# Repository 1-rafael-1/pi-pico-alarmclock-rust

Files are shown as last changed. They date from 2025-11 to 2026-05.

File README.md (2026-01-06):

# Raspberry Pi Pico Alarmclock written in Rust



A fully-featured alarm clock built on a Raspberry Pi Pico W, written in Rust using the Embassy async framework.

<div align="center">
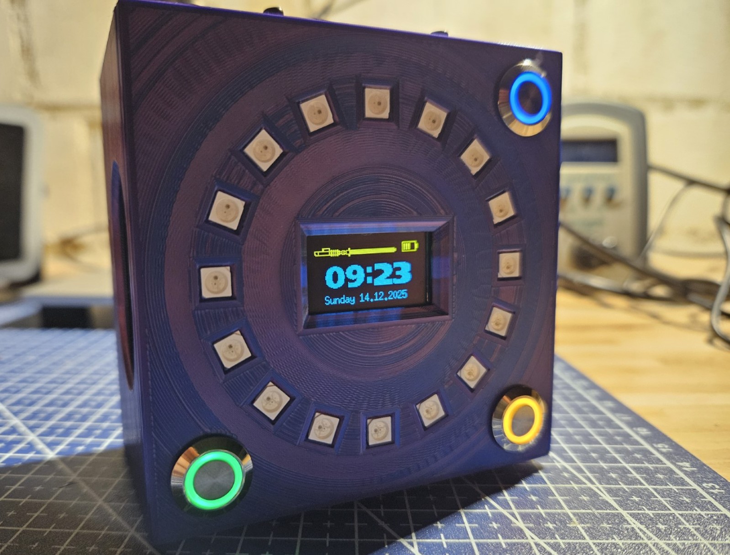
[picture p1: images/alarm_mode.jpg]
Alarm clock with alarm enabled
  
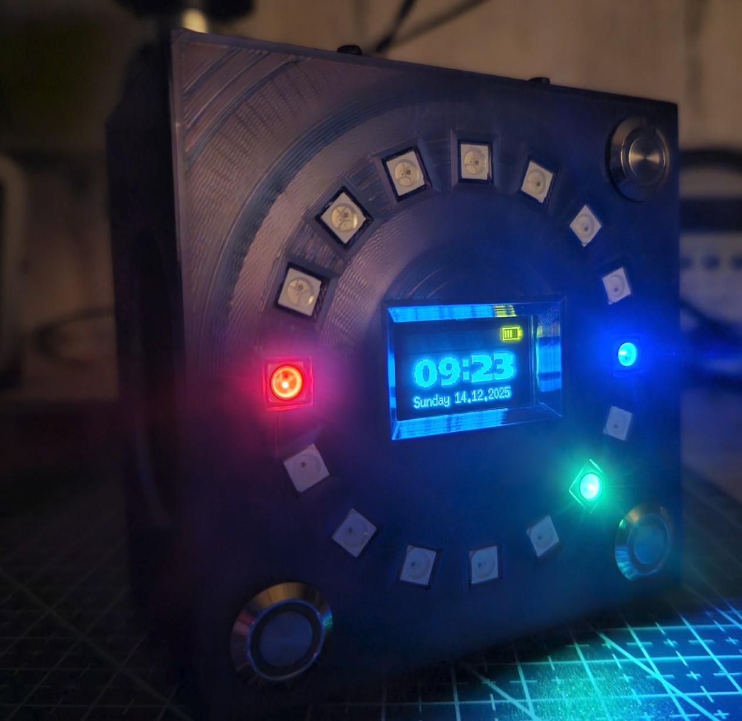
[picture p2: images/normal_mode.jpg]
Finished alarm clock front view
  
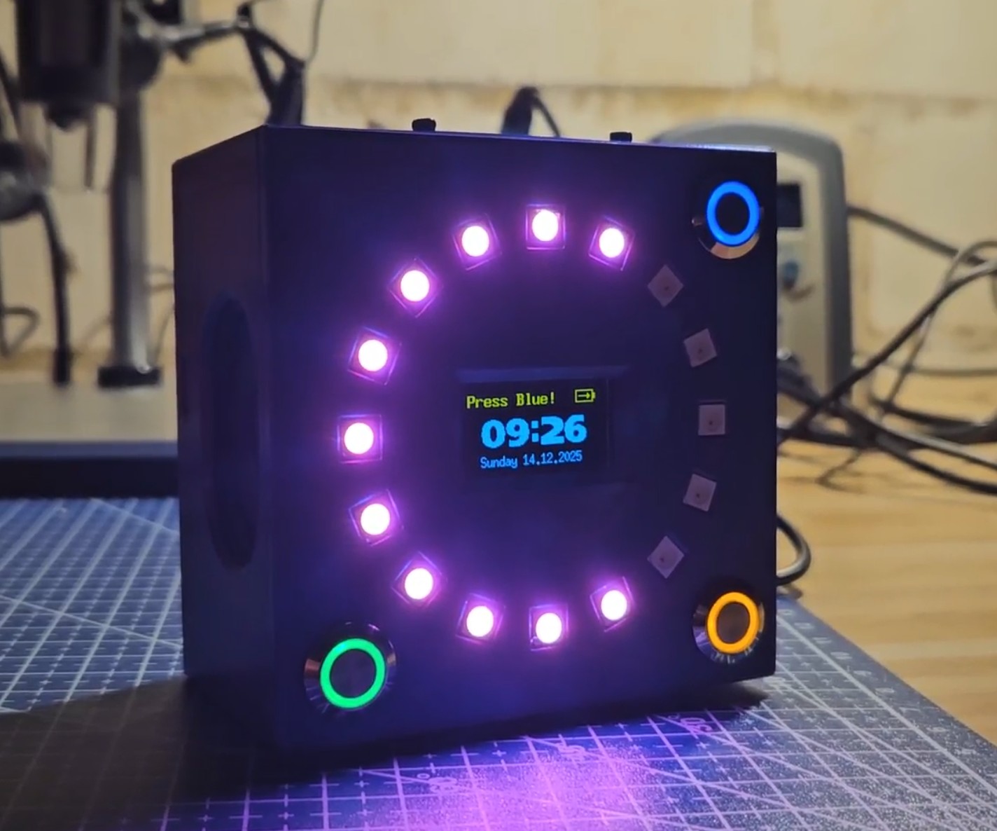
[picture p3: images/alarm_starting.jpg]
Finished alarm clock with LEDs active
  
</div>

*Left: Alarm enabled with lightsaber icon indicator. Center: The completed alarm clock showing the OLED display, NeoPixel ring with hour markers, and three illuminated control buttons (green, blue, yellow). Right: Alarm clock in operation with active NeoPixel LEDs displaying the analog clock.*

---

## Features at a Glance

### Core Functionality
- **WiFi Time Sync** - Automatic time synchronization via worldtimeapi.org (refreshed every 6 hours)
- **Alarm System** - Configurable alarm with sunrise light effect and audio playback
- **Visual Display** - 128×64 OLED display with custom Star Wars-inspired font
- **Analog Clock** - 16-LED NeoPixel ring showing hours (red), minutes (green), and seconds (blue)
- **Battery Powered** - 18650 Li-ion battery with USB charging and voltage monitoring

### User-Configurable Settings
- **Volume Control** (0-30) - Adjustable alarm sound volume, persisted to flash
- **LED Brightness** (0-20) - Adjustable NeoPixel clock brightness with live preview
- **Manual Time Setting** - Set time via buttons when WiFi unavailable or for DST adjustments

### Advanced Features
- **Multi-Mode Interface** - Normal, Menu, Settings, Alarm, System Info, and Standby modes
- **Smart Alarm** - Sunrise light effect followed by audio, with randomized button sequence to dismiss
- **Auto-Timeout Protection** - All menus and settings automatically return to Normal mode after 10 seconds of inactivity (with auto-save)
- **Power Management** - Standby mode with task suspension for minimal power consumption
- **Persistent Storage** - All settings saved to flash memory and survive power cycles

---

## Quick Start

### Build and Flash

This project uses **probe-rs** for debugging and flashing via a debug probe (e.g., Raspberry Pi Debug Probe, Picoprobe).

```bash
# Build and flash with probe-rs (recommended)
DEFMT_LOG=warn cargo run --release
```

See the [Building the Project](#building-the-project) section for more details.

### First Use

1. Power on the device - it will initialize and sync time via WiFi
2. Press **Yellow** to open the menu
3. Press **Green** to access Settings
4. Configure your preferences (volume, brightness, etc.)
5. Press **Blue** in Normal mode to set your alarm time
6. Press **Green** in Normal mode to toggle the alarm on/off

See the [User Manual](#user-manual) below for detailed instructions.

---

## Hardware Components

### Main Components
- Raspberry Pi Pico W (microcontroller with WiFi)
- SSD1306 OLED Display (128×64 pixels, I²C)
- DFPlayer Mini MP3 module (DFR0299)
- WS2812B NeoPixel Ring (16 RGB LEDs)
- 3W 8Ω Speaker
- 18650 Li-ion Battery (3350mAh)
- TC4056A Charger Module
- 5V Step-up Converter

### Interface
- 3× LED Ring Push Buttons (12mm, Green/Blue/Yellow)
- Micro SD card (FAT32, for alarm audio)

Complete bill of materials available in the [Components](#components-bill-of-materials) section below.

---

## Project Structure

The project is written in Rust using the Embassy async framework:

- **`src/state.rs`** - System state management
- **`src/event.rs`** - Event channel and event types
- **`src/task/`** - Async tasks for each peripheral and system function
  - `orchestrate.rs` - Central orchestration and state transitions
  - `display.rs` - OLED display management
  - `light_effects.rs` - NeoPixel LED control
  - `sound.rs` - DFPlayer audio control
  - `rtc_manager.rs` - Real-time clock management
  - `alarm_settings.rs` - Flash persistence for settings
  - `time_updater.rs` - WiFi time synchronization
  - And more...
- **`src/utility/`** - Helper functions (DateTime conversion, etc.)
- **`media/`** - Custom BMP graphics for display
- **`circuit/`** - KiCad schematic and PCB design
- **`enclosure/`** - FreeCAD 1.0 design files

### Documentation

```bash
# Generate and view code documentation
cargo doc --open
```

---

## Building the Project

This project uses `defmt` for logging. Log levels are controlled by the `DEFMT_LOG` environment variable.

### Development Build

For development with full logging (requires debug probe):

```bash
cargo build
cargo run
```

### Release Build

**Warnings only** (prevents RTT buffer overflow when running standalone):

```bash
DEFMT_LOG=warn cargo build --release
DEFMT_LOG=warn cargo run --release
```

**Moderate logging** (info and above):

```bash
DEFMT_LOG=info cargo build --release
```

## User Manual

### Button Layout

- **Green Button** (left)
- **Blue Button** (middle)
- **Yellow Button** (right)

---

### Normal Mode (Clock Display)

This is the default mode showing the current time.

| Button | Action |
|---|---|
| **Green** | Toggle alarm ON/OFF |
| **Blue** | Enter alarm time setting |
| **Yellow** | Open menu |

**Display shows:**
- Current time (large Star Wars font digits)
- Date and day of week
- Lightsaber icon (if alarm is active)
- Battery level or USB charging indicator

**NeoPixel ring:**
- Red LED = hour hand
- Green LED = minute hand
- Blue LED = second hand
- Colors mix when hands overlap

---

### Setting the Alarm Time

| Button | Action |
|---|---|
| **Green** | Increase hours (+1, wraps 23→0) |
| **Yellow** | Increase minutes (+1, wraps 59→0) |
| **Blue** | Save and return to Normal mode |

**Tips:**
- Hold button for continuous increment
- Time wraps around for easy adjustment
- Alarm setting is saved to flash automatically
- **Auto-timeout:** Returns to Normal mode after 10 seconds of inactivity (changes are saved)

---

### Menu

Press **Yellow** from Normal mode to access the menu.

| Button | Action |
|---|---|
| **Green** | **Settings Menu** |
| **Blue** | **Standby Mode** |
| **Yellow** | System Info |

**Auto-timeout:** Returns to Normal mode after 10 seconds of inactivity

---

### Settings Menu

Configure volume, brightness, and time.

| Button | Action |
|---|---|
| **Green** | Set Volume |
| **Blue** | Set LED Brightness |
| **Yellow** | Set Time Manually |

**Auto-timeout:** Returns to Normal mode after 10 seconds of inactivity

---

### Set Volume

Adjust alarm sound volume (0-30).

| Button | Action |
|---|---|
| **Green** | Increase volume (+1, wraps 30→0) |
| **Yellow** | Decrease volume (-1, wraps 0→30) |
| **Blue** | **Save to flash** and return to Settings Menu |

**Display shows:** `Volume: 13`

**Range:** 0-30 (DFPlayer Mini volume range)

**Auto-timeout:** Auto-saves and returns to Normal mode after 10 seconds of inactivity

---

### Set LED Brightness

Adjust NeoPixel clock brightness (0-20).

| Button | Action |
|---|---|
| **Green** | Increase brightness (+1, wraps 20→0) |
| **Yellow** | Decrease brightness (-1, wraps 0→20) |
| **Blue** | **Save to flash** and return to Settings Menu |

**Display shows:** `LED Clock: 1`

**Range:** 0-20 (limited for battery safety)

**Live Preview:** Clock LEDs update immediately as you adjust!

**Auto-timeout:** Auto-saves and returns to Normal mode after 10 seconds of inactivity

---

### Set Time Manually

Set time when WiFi is unavailable or for DST adjustments.

| Button | Action |
|---|---|
| **Green** | Increase hours (+1, wraps 23→0) |
| **Yellow** | Increase minutes (+1, wraps 59→0) |
| **Blue** | **Set RTC** and return to Settings Menu |

**Display shows:** Time in large digits (HH:MM)

**Note:** Seconds are reset to :00, date is preserved from current RTC

**Auto-timeout:** Auto-saves and returns to Normal mode after 10 seconds of inactivity

---

### System Info

View power and alarm information (2 pages).

**Page 1 - Power Info:**
- Vsys voltage
- USB power status
- Firmware version

**Page 2 - Alarm Info:**
- Alarm time
- Next trigger date
- Enabled status

| Button | Action |
|---|---|
| **Green** | Next page (or exit if on last page) |
| **Blue** | Back to Normal mode |
| **Yellow** | Back to Normal mode |

**Auto-timeout:** Returns to Normal mode after 10 seconds of inactivity

---

### Alarm Triggered

When the alarm goes off:

1. **Sunrise Effect** - NeoPixel ring gradually lights up (morning red → warm white)
2. **Audio Playback** - Imperial March plays once
3. **Waker Effect** - Rainbow whirl on NeoPixel ring
4. **Dismissal Challenge** - Must press randomized button sequence

**Display shows:** `Press Yellow!` (or Green/Blue - changes each time)

| Button | Action |
|---|---|
| **Any** | Press the **requested color** in the correct sequence |

**Must press all 3 colors in the correct order to stop the alarm!**

---

### Standby Mode

Power-saving mode with display and LEDs off.

**To enter:** Menu → Blue button

**Display shows:** "Going to sleep..." (briefly)

**What's suspended:**
- Display updates
- NeoPixel ring
- Scheduler task
- Time updater task
- Voltage measurement task

| Button | Action |
|---|---|
| **Any** | Wake up device |

**On wake:** All tasks resume and time sync is performed.

---

### Common Patterns

**Navigation:**
- **Yellow** = "Back" or "Next option"
- **Blue** = "Confirm/Save"
- **Green** = "Primary action" or "Increase"

**Adjusting Values:**
- **Green** = Increment/Increase
- **Yellow** = Decrement/Decrease
- **Blue** = Save/Confirm

**Wrapping Behavior:**
All numeric values wrap around for easy adjustment:
- Hours: 23 → 0
- Minutes: 59 → 0
- Volume: 30 → 0
- Brightness: 20 → 0

---

### Tips and Tricks

1. **Settings Persist** - Volume and brightness are saved to flash and survive power cycles
2. **Live Preview** - LED brightness changes are visible immediately while adjusting
3. **No Confirmation Prompts** - Pressing Blue always saves/confirms
4. **Auto-Timeout Protection** - All menus and settings automatically return to Normal mode after 10 seconds of inactivity (settings are auto-saved)
5. **WiFi Not Required** - Manual time setting works even if WiFi is down
6. **Alarm Preserved** - Setting time manually doesn't affect your alarm settings
7. **Hold for Speed** - Hold Green or Yellow buttons for continuous increment

---

## Circuit Design

Circuit schematic available in KiCad format: [circuit/pi-pico-alarmclock/](circuit/pi-pico-alarmclock/)

Design includes:
- Power management with battery charger
- Voltage level sensing
- MOSFET switching for display and audio control
- All peripheral connections

---

## Enclosure

Designed in FreeCAD 1.0. Export files available: [enclosure/](enclosure/)

### Enclosure CAD View
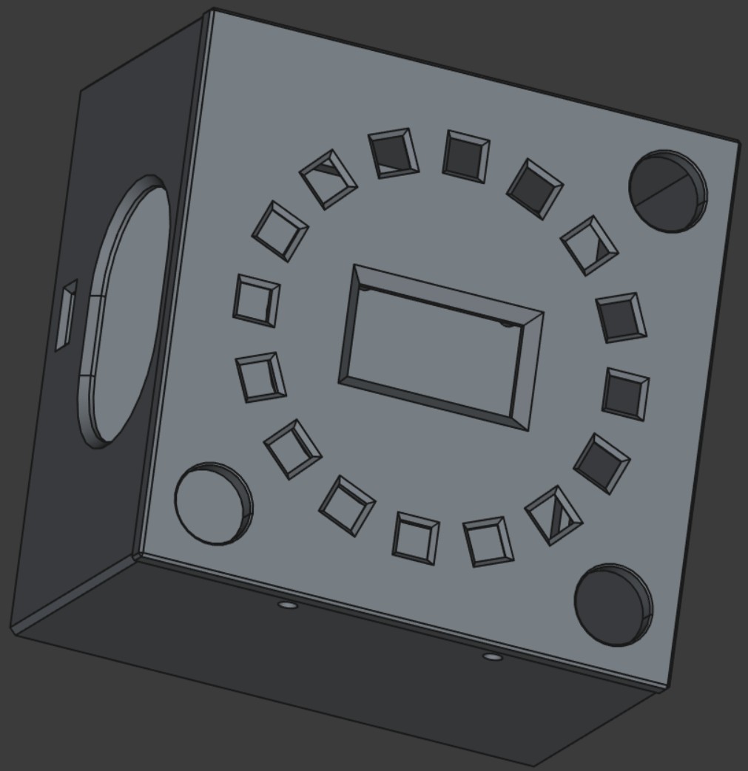
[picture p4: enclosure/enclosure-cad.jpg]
Enclosure CAD


*External view of the enclosure showing the front panel with OLED display cutout, NeoPixel ring hour markers, speaker grille, rotary encoder, and push button positions.*

### Assembly View
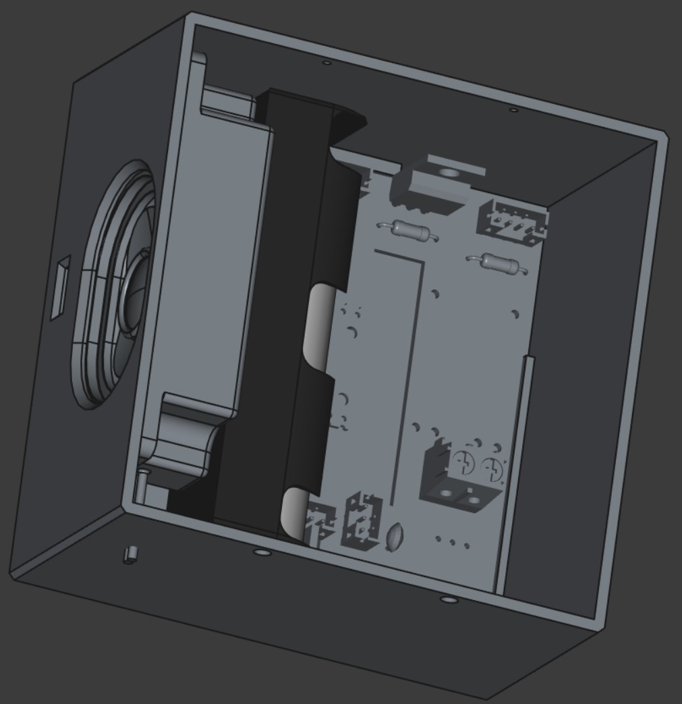
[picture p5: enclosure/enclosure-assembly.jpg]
Enclosure Assembly


*Interior assembly view with lid removed, showing PCB placement, speaker mounting, and 18650 battery holder positioning.*

---

## Assembly

### Breadboard Prototype
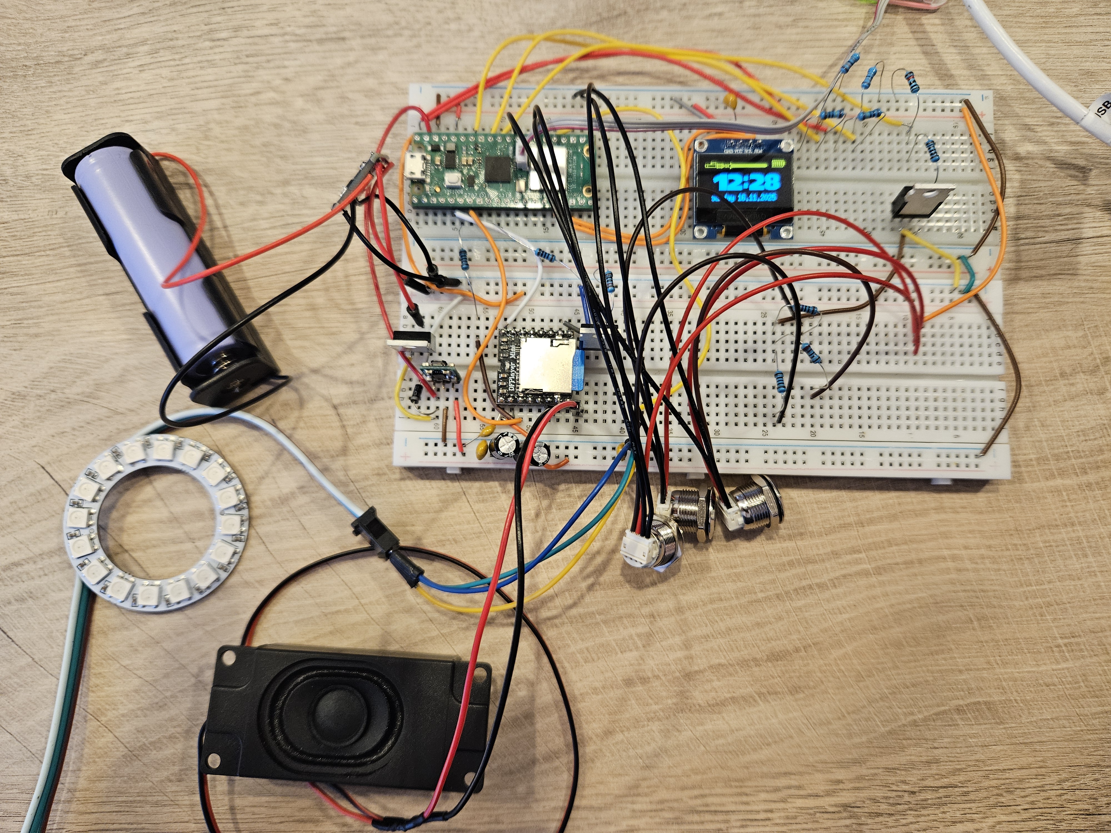
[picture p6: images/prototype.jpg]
Breadboard Prototype


*Early breadboard prototype used for development and testing of the circuit design before moving to the final PCB implementation.*

### Finished Build
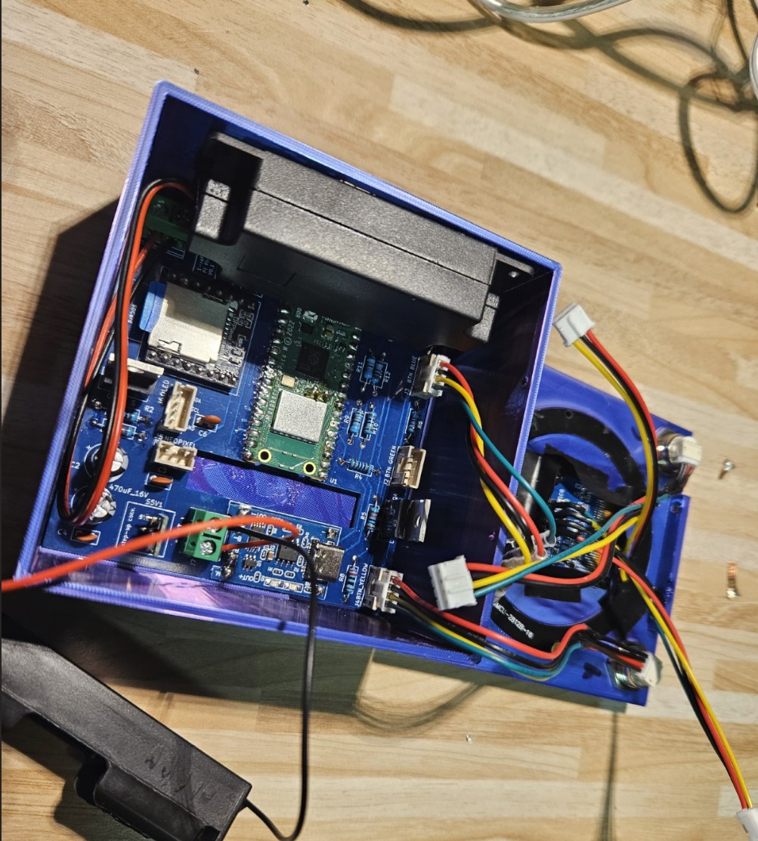
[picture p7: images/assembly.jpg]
Finished Build


*The completed alarm clock showing the internal assembly with custom PCB, Raspberry Pi Pico W mounted on the controller board, DFPlayer Mini MP3 module, NeoPixel ring, speaker, 18650 battery, and wiring for the three LED ring push buttons.*

---

## Components (Bill of Materials)

### Main Components
|Component|Qty|Description|
|---|---|---|
|Raspberry Pi Pico W|1|Microcontroller with WiFi|
|OLED Display|1|SSD1306 compatible I²C OLED Display 128×64 pixels with two color yellow/blue. Input Voltage 3.3V|
|DFPlayer Mini|1|MP3 module (DFR0299)|
|TC4056A Charger Module|1|Li-ion battery charging module with protection|
|Step-up Converter|1|5V boost converter (e.g., U3V16F5 or similar), 2.5-5.5V input, 5V/1A output|
|WS2812B NeoPixel Ring|1|16 RGB LED ring (this is the limit the power supply can handle)|
|Speaker|1|3W 8Ω speaker, 70×30×15mm (DFPlayer Mini compatible)|
|18650 Li-ion Battery|1|3350mAh or similar capacity|
|Battery Holder|1|For 18650 battery|
|Micro SD Card|1|Any capacity, formatted to FAT32|

### Push Buttons
|Component|Qty|Description|
|---|---|---|
|LED Ring Push Buttons|3|12mm LED ring illuminated push buttons with JST 4-pin connectors (one each: yellow, green, blue). LED rings are controlled via MOSFET Q4 (IRLZ44N) on GPIO 26 with 10-second auto-off timeout on button press (except during alarm mode)|

### Semiconductors
|Component|Qty|Type|Description|
|---|---|----|---|
|Q1, Q2, Q4|3|IRLZ44N|N-channel MOSFET, logic-level (TO-220)|
|Q3|1|IRF9540|P-channel MOSFET, logic-level (TO-220)|
|D3|1|1N5819|Schottky diode, 40V, 1A (DO-41)|

### Resistors (1/4W)
|Reference|Qty|Value|
|---|---|-----|
|R1, R5, R14|3|10kΩ|
|R2, R13|2|100Ω|
|R3, R7|2|1kΩ|
|R6|1|2.2kΩ|
|R8|1|220Ω|
|R9, R11|2|100kΩ|
|R10, R12|2|220kΩ|

### Capacitors
|Reference|Qty|Type|Value|Voltage|Description|
|---|---|----|-----|---|---|
|C1, C3, C4, C5, C6|5|Ceramic|100nF|50V|General decoupling|
|C2, C7|2|Electrolytic|470µF|16V|Power supply filtering|
|C8, C9|2|Ceramic|100nF|50V|ADC input filters for VSYS/VBUS voltage dividers|

### Connectors
|Reference|Qty|Type|Description|
|---|---|----|---|
|J1|1|Screw Terminal 2P|5mm pitch, for speaker connection|
|J2|1|JST PH 4-pin|Button Green (2mm pitch)|
|J3|1|JST PH 4-pin|Button Blue (2mm pitch)|
|J4|1|JST PH 4-pin|Button Yellow (2mm pitch)|
|J5|1|JST PH 3-pin|NeoPixel connection (2mm pitch)|
|J6|1|JST PH 4-pin|OLED display (2mm pitch)|
|J7|1|Screw Terminal 2P|5mm pitch, for battery connection|

---

## Technical Details

### Power Detection Noise Filtering

The USB power and battery voltage detection uses voltage dividers (220kΩ/100kΩ) with 100nF filter capacitors that help reduce electrical noise from NeoPixel switching and EMI in the enclosure. Software filtering further improves stability:

**USB Detection (VBUS):**
- Debouncing with 5 consecutive readings
- 10ms delay between samples
- Rejects transient noise spikes

**Voltage Measurement (VSYS):**
- Median filter for ADC samples (rejects impulse noise spikes)
- 5ms settling delay between samples
- 0.1V hysteresis to prevent display flicker

### Flash Memory Layout

Settings are stored using sequential-storage with wear leveling:

| Key | Setting | Type | Range | Default |
|-----|---|---|---|---|
| 0 | Alarm Hour | u8 | 0-23 | 0 |
| 1 | Alarm Minute | u8 | 0-59 | 0 |
| 2 | Alarm Enabled | u8 | 0-1 | 0 (false) |
| 3 | Volume | u8 | 0-30 | 13 |
| 4 | Clock Brightness | u8 | 0-20 | 1 |

**Flash Range:** `0x1F_9000..0x1FC_000` (12K allocated)

**Memory Configuration:**
- Total Flash: 2048K (2 MB)
- Code: 2020K
- Settings: 12K
- Reserved: 16K

---

## Lessons Learned for Future Iterations

This project worked well as a learning experience, but there are several hardware design decisions that should be improved in a future version:

### Power Management Issues

**1. No Hardware Power Switch**
- The device lacks a physical power switch, relying entirely on software standby mode
- This means the device continuously draws power even when "off"
- **Solution for next version:** Add a physical power switch between the battery and the circuit OR even better add circuitry to power down and back up by push button, AFAIK that is possible but was out of my league for this iteration.

## Acknowledgments

This is a hobby project and I have very little experience in electronics and had none before in Rust and also none before in CAD. All three things I taught myself along the way. While this was incredible fun, this project will be full of imperfections, literally everywhere. In case you happen across this repo and spots a thing to improve - if you find the time to let me know, I will be more than happy. After all, this was and is about learning things.

That being said: This device does work, at least as far as I did test it to this point.

Does the world need another alarm clock? Hell no, it does not. You can buy them in thousands of types for very little money and then most will have more functionality, better battery life, and whatnot. I was looking for a thing to do, had a joking conversation with my eldest daughter (who is in an age range where getting up in the morning appears to be terribly difficult) and that was that: I found myself building this thing.

It took me two years, much of which time this project sat in some state of being unfinished. Mostly it sat idle when I had hit a wall in Rust-skill, electronics skill or 3d-printing skill. I only very recently found a huge ground bounce that messed up the DFPlayer audio output.

When I started this, Coding AI was in relative infancy. I am glad it was, because that made me learn a lot the hard and memorable way. By today all that I do uses AI to some extent, it is amazing what kind of reach this bestows. So, in this iteration of the project I did use AI for almost all refactoring and - shame on me - also for some features. Would I dare to if this was a commercial project? No. But for a hobby thing? Why not?

## Thanks

- **[Embassy Framework](https://github.com/embassy-rs/embassy)** - Rust async framework for embedded devices with excellent examples and HALs
- **Embassy Community** - Patient and helpful individuals who answered my Rust-rookie and Embassy-rookie questions. From the orchestrator pattern through a number of headscratchers with Cells, Mutexes and Sync Primitives.... I learned it all from them.

## License

MIT License - See [LICENSE](LICENSE) file for details

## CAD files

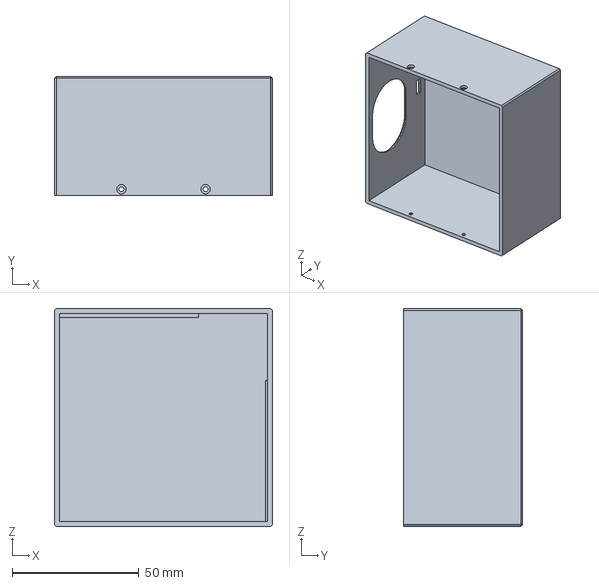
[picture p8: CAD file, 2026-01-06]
enclosure/PiPicoAlarmclock-Body.3mf
86.0 x 47.0 x 86.0 mm

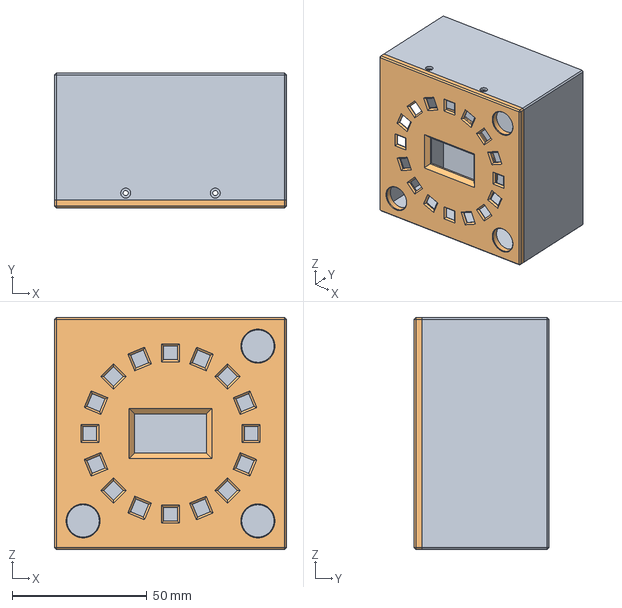
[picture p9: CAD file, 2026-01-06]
enclosure/PiPicoAlarmclock.FCStd
86.0 x 50.0 x 86.0 mm
Front

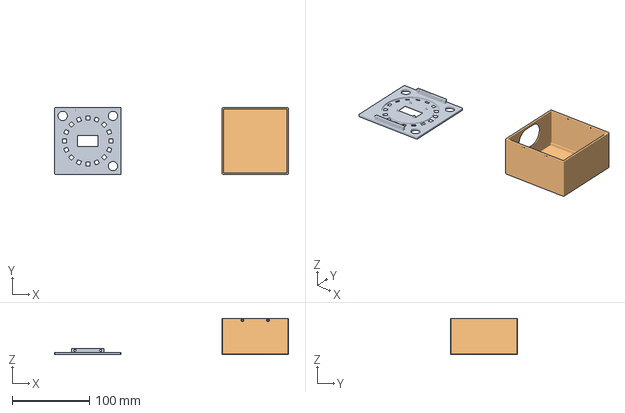
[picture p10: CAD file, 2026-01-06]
enclosure/print.3mf
302.0 x 86.0 x 47.0 mm

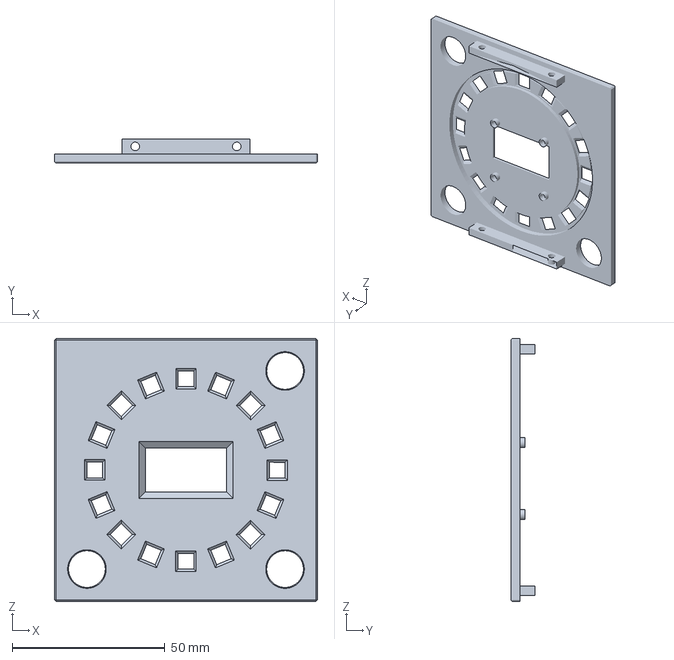
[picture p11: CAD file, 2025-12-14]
enclosure/PiPicoAlarmclock-Front.3mf
86.0 x 8.00 x 86.0 mm

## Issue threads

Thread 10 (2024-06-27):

joining wifi stalls the system

1-rafael-1, 2024-06-27:

Closed 2024-06-27.

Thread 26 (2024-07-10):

pattern to orchestrate the tasks throughout the application

1-rafael-1, 2024-07-10:
In the MicroPython alarmclock we used OOP pattern dependency injection to centralize the flow of the application. In this project here with all its async tasks this does not lend itself well.

General thought, as picked up on matrix from Hendrik Alser:
- event enum
- have aan event channel based on that, which all the prod tasks post to
- have one hub task (can be main) receive all that and dispatch handler fns or itself notify the prod tasks that stuff has changed.

In this case here for example:
- the alarm is raised, send the info to the hub
- hub notifies both alarm sound task as well as alarm neopixel task, that they should start yelling

... and so forth

1-rafael-1, 2024-07-10:
maybe combine with https://crates.io/crates/fieldset
-> state struct for readability

Closed 2024-07-24.

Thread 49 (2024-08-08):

buttons are not responsive enough

1-rafael-1, 2024-08-08:
buttons do work, but i believe the implementation is flawed.
Ideally: less debounce time, more snappy reaction in all modes except when setting alarm time. In that latter case we should be able to hold the button down and stream updates continuously.

Closed 2024-08-17.

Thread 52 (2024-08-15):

alarm never stops

1-rafael-1, 2024-08-15:
If the alarm is raised, it never ever ends again on its own. That is not ideal, maybe after 10 minutes we must give up on the idea of waking a kid in puberty and resort to a water bucket, while this alarm clock resets to normal operation.

Closed 2024-08-17.

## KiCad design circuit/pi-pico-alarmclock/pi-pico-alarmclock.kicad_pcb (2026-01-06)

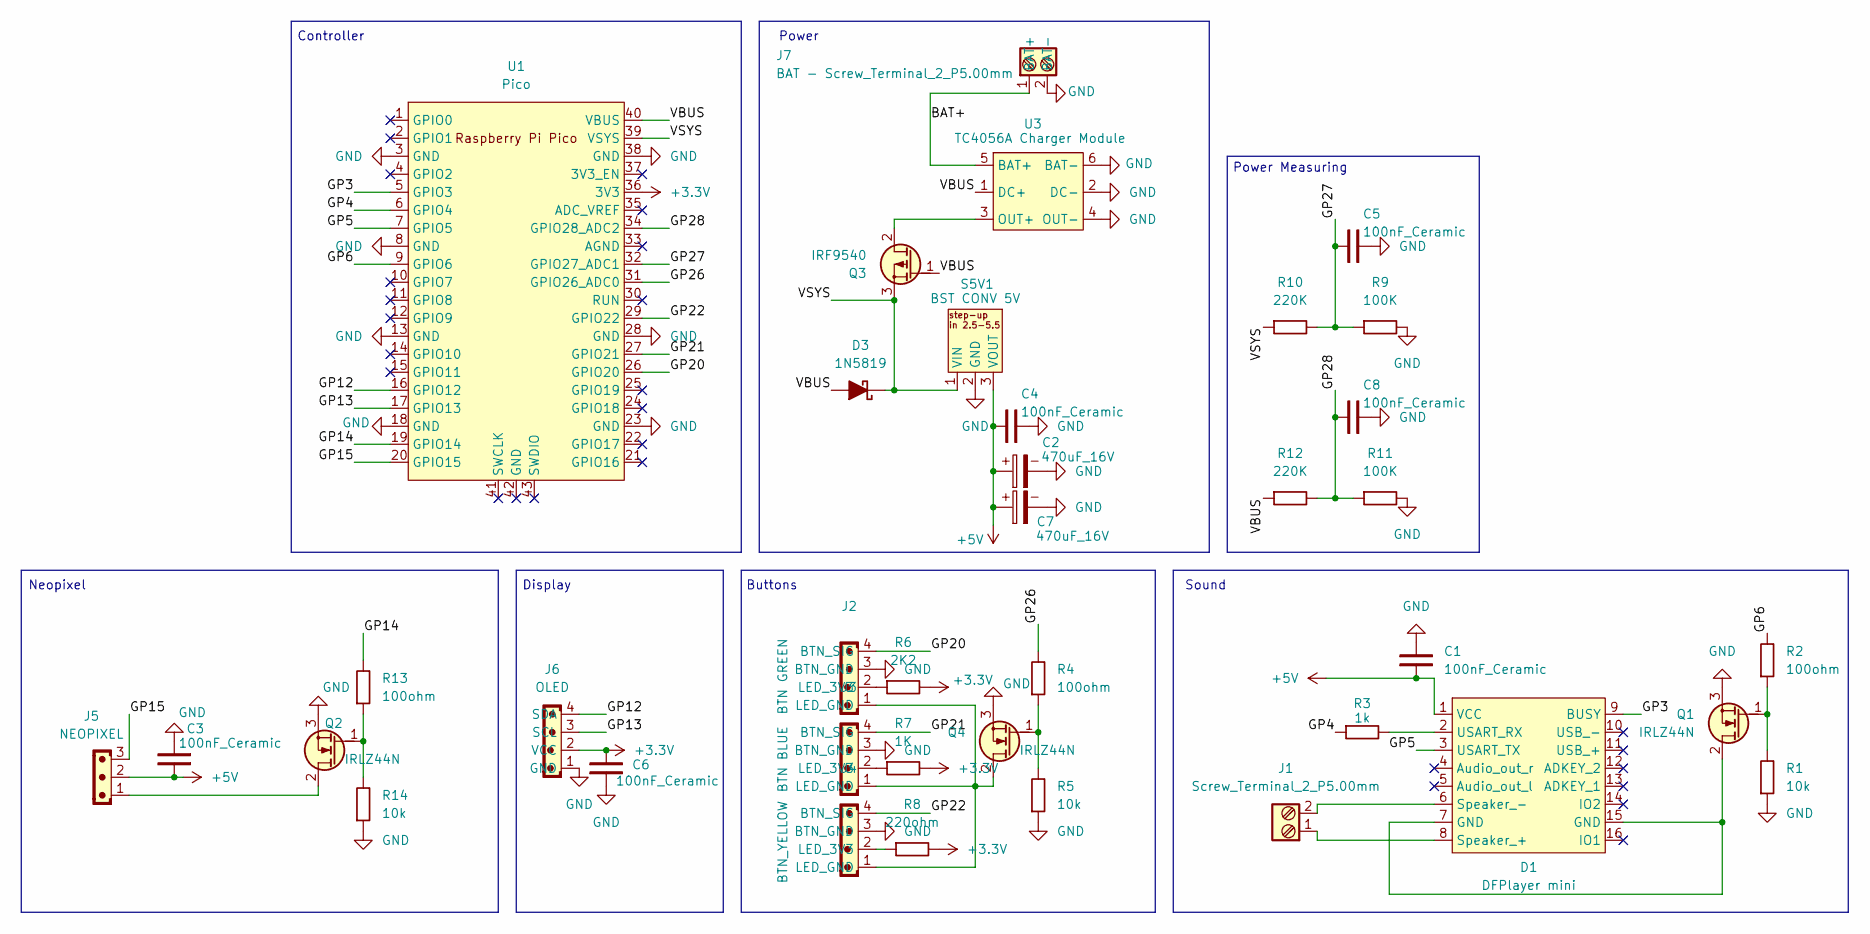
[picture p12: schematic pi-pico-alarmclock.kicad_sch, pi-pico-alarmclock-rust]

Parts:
C1, C3, C4, C5, C6, C8: 100nF_Ceramic; C_Disc_D5.0mm_W2.5mm_P2.50mm
C2, C7: 470uF_16V; CP_Radial_D8.0mm_P3.50mm
D1: DFPlayer mini
D3: 1N5819; D_DO-41_SOD81_P7.62mm_Horizontal
J1: Screw_Terminal_2_P5.00mm; TerminalBlock_Phoenix_PT-1,5-2-5.0-H_1x02_P5.00mm_Horizontal
J2: BTN GREEN; JST_PH_B4B-PH-K_1x04_P2.00mm_Vertical
J3: BTN BLUE; JST_PH_B4B-PH-K_1x04_P2.00mm_Vertical
J4: BTN_YELLOW; JST_PH_B4B-PH-K_1x04_P2.00mm_Vertical
J5: NEOPIXEL; JST_PH_B3B-PH-K_1x03_P2.00mm_Vertical
J6: OLED; JST_PH_B4B-PH-K_1x04_P2.00mm_Vertical
J7: BAT - Screw_Terminal_2_P5.00mm; TerminalBlock_Phoenix_PT-1,5-2-5.0-H_1x02_P5.00mm_Horizontal
Q1, Q2, Q4: IRLZ44N; TO-220-3_Vertical_GDS
Q3: IRF9540; TO-220-3_Vertical_GDS
R1, R5, R14: 10k; R_Axial_DIN0207_L6.3mm_D2.5mm_P10.16mm_Horizontal
R2, R4, R13: 100ohm; R_Axial_DIN0207_L6.3mm_D2.5mm_P10.16mm_Horizontal
R3: 1k; R_Axial_DIN0207_L6.3mm_D2.5mm_P10.16mm_Horizontal
R6: 2K2; R_Axial_DIN0207_L6.3mm_D2.5mm_P10.16mm_Horizontal
R7: 1K; R_Axial_DIN0207_L6.3mm_D2.5mm_P10.16mm_Horizontal
R8: 220ohm; R_Axial_DIN0207_L6.3mm_D2.5mm_P10.16mm_Horizontal
R9, R11: 100K; R_Axial_DIN0207_L6.3mm_D2.5mm_P10.16mm_Horizontal
R10, R12: 220K; R_Axial_DIN0207_L6.3mm_D2.5mm_P10.16mm_Horizontal
S5V1: BST CONV 5V; Pololu step-up converter 2.5-5.5V in 5V out
U1: Pico; RaspberryPi_Pico_W_SMD_HandSolder
U3: TC4056A Charger Module; TP4056_charger_board

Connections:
+3.3V: C6.2, J6.2 (VCC), R6.2, R7.2, R8.2, U1.36 (3V3)
+5V: C1.1, C2.1, C3.2, C4.2, C7.1, D1.1 (VCC), J5.2, S5V1.3 (VOUT)
/BAT+: J7.1 (BAT+), U3.5 (BAT+)
/GP3: D1.9 (BUSY), U1.5 (GPIO3)
/GP4: R3.1, U1.6 (GPIO4)
/GP5: D1.3 (USART_TX), U1.7 (GPIO5)
/GP6: R2.2, U1.9 (GPIO6)
/GP12: J6.4 (SDA), U1.16 (GPIO12)
/GP13: J6.3 (SCL), U1.17 (GPIO13)
/GP14: R13.2, U1.19 (GPIO14)
/GP15: J5.3, U1.20 (GPIO15)
/GP20: J2.4 (BTN_SIG), U1.26 (GPIO20)
/GP21: J3.4 (BTN_SIG), U1.27 (GPIO21)
/GP22: J4.4 (BTN_SIG), U1.29 (GPIO22)
/GP26: R4.2, U1.31 (GPIO26_ADC0)
/GP27: C5.2, R9.1, R10.2, U1.32 (GPIO27_ADC1)
/GP28: C8.2, R11.1, R12.2, U1.34 (GPIO28_ADC2)
/VBUS: D3.2 (A), Q3.1 (G), R12.1, U1.40 (VBUS), U3.1 (DC+)
/VSYS: D3.1 (K), Q3.3 (S), R10.1, S5V1.1 (VIN), U1.39 (VSYS)
GND: C1.2, C2.2, C3.1, C4.1, C5.1, C6.1, C7.2, C8.1, J2.3 (BTN_GND), J3.3 (BTN_GND), J4.3 (BTN_GND), J6.1 (GND), J7.2 (BAT-), Q1.3 (S), Q2.3 (S), Q4.3 (S), R1.1, R5.1, R9.2, R11.2, R14.1, S5V1.2 (GND), U1.3 (GND), U1.8 (GND), U1.13 (GND), U1.18 (GND), U1.23 (GND), U1.28 (GND), U1.38 (GND), U3.2 (DC-), U3.4 (OUT-), U3.6 (BAT-)
unnamed: D1.8 (Speaker_+), J1.1
unnamed: D1.6 (Speaker_-), J1.2
unnamed: D1.2 (USART_RX), R3.2
unnamed: J2.2 (LED_3V3), R6.1
unnamed: J2.1 (LED_GND), J3.1 (LED_GND), J4.1 (LED_GND), Q4.2 (D)
unnamed: J3.2 (LED_3V3), R7.1
unnamed: J4.2 (LED_3V3), R8.1
unnamed: D1.7 (GND), D1.15 (GND), Q1.2 (D)
unnamed: Q1.1 (G), R1.2, R2.1
unnamed: J5.1, Q2.2 (D)
unnamed: Q2.1 (G), R13.1, R14.2
unnamed: Q3.2 (D), U3.3 (OUT+)
unnamed: Q4.1 (G), R4.1, R5.2

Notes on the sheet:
Power Measuring
Display
Neopixel
Sound
Buttons
Power
Controller

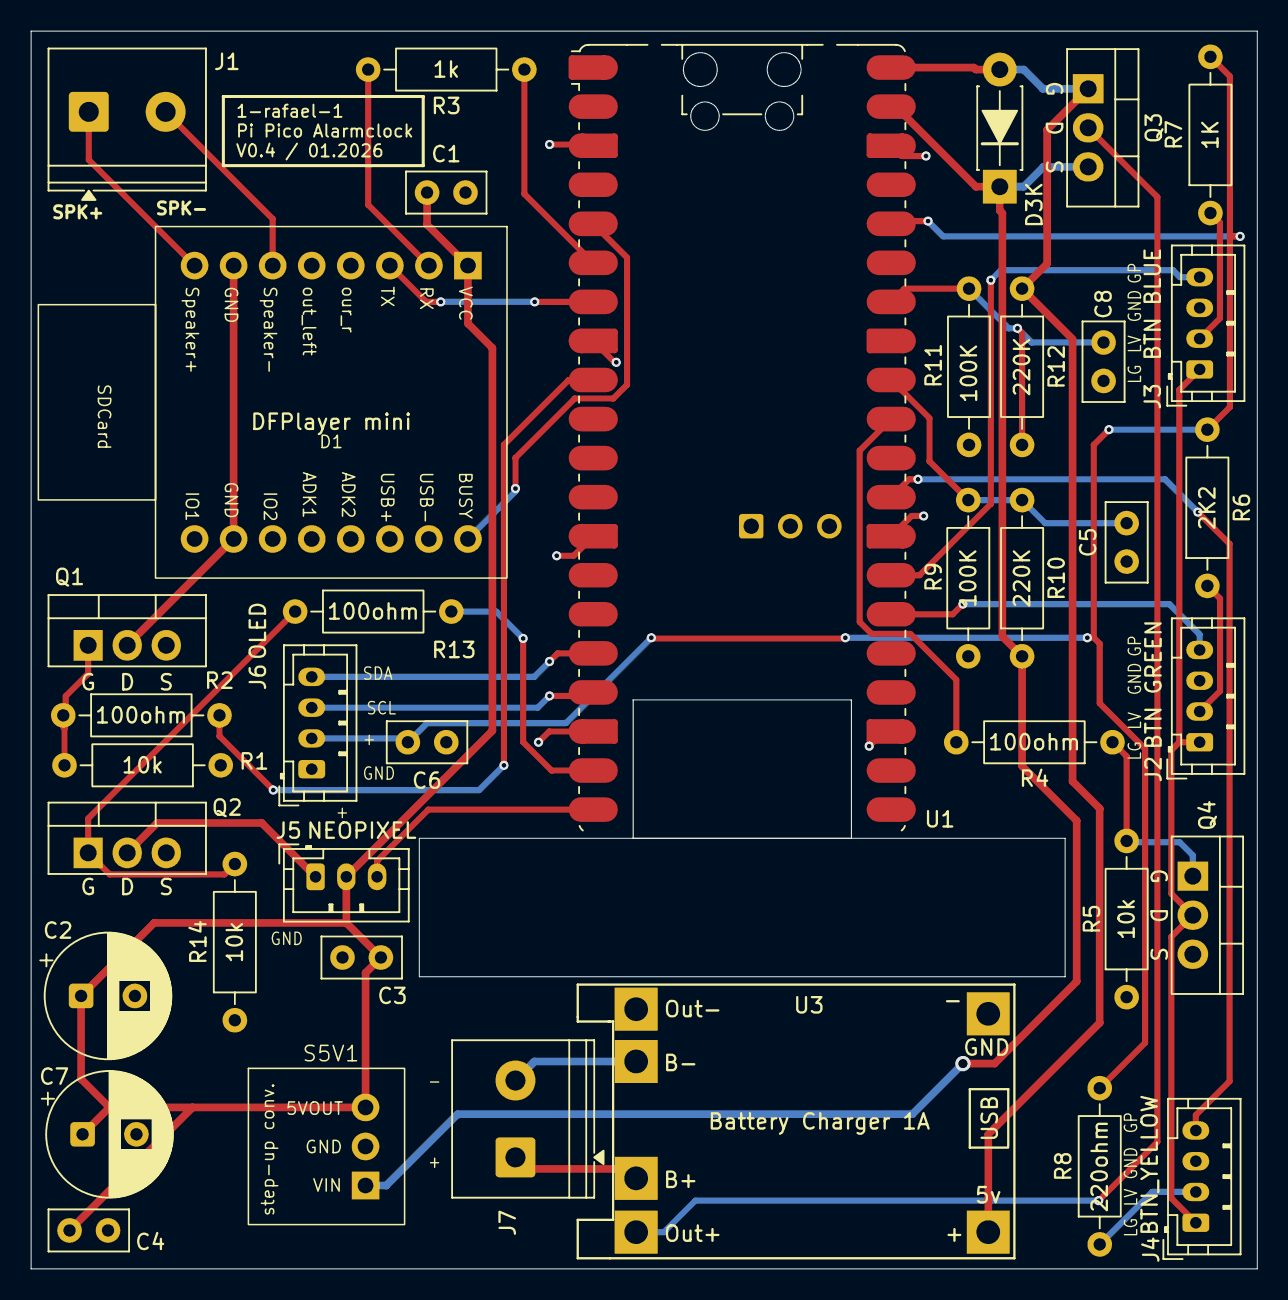
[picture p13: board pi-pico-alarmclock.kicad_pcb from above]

Board: 2 copper layers, 79.8 x 80.5 mm, 38 parts (0 on the bottom side), 33 nets.

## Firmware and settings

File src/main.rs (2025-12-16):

//! # Main
//! This is the main entry point of the program.
//! we are in an environment with constrained resources, so we do not use the standard library and we define a different entry point.
#![no_std]
#![no_main]

use defmt::info;
use defmt_rtt as _;
use embassy_executor::{Spawner, main};
use embassy_rp::{
    adc::{Adc, Channel, Config as AdcConfig, InterruptHandler as AdcInterruptHandler},
    bind_interrupts,
    clocks::{ClockConfig, CoreVoltage},
    config::Config,
    flash::{Async, Flash},
    gpio::{Input, Level, Output, Pull},
    i2c::{Config as I2cConfig, I2c, InterruptHandler as I2cInterruptHandler},
    peripherals::{I2C0, PIO0, PIO1, UART1},
    pio::{InterruptHandler as PioInterruptHandler, Pio},
    pio_programs::ws2812::{PioWs2812, PioWs2812Program},
    rtc::{InterruptHandler as RtcInterruptHandler, Rtc},
    uart::{BufferedInterruptHandler, BufferedUart, Config as UartConfig},
};
use panic_probe as _;
use static_cell::StaticCell;

use crate::{
    event::Event,
    task::{
        alarm_settings::alarm_settings_handler,
        alarm_trigger::alarm_trigger_task,
        button_leds::button_leds_handler,
        buttons::{Button, button_handler},
        display::display_handler,
        light_effects::light_effects_handler,
        orchestrate::{orchestrator, scheduler},
        power::{usb_power_detector, vsys_voltage_reader},
        rtc_manager::rtc_manager_task,
        sound::sound_handler,
        time_updater::time_updater,
        watchdog::watchdog_task,
    },
};

mod event;
mod state;
mod task;
mod utility;

/// Firmware version - automatically populated from Cargo.toml
pub static FIRMWARE_VERSION: &str = env!("CARGO_PKG_VERSION");

// Bind the interrupts on a global scope for convenience
bind_interrupts!(pub struct Irqs {
    PIO0_IRQ_0 => PioInterruptHandler<PIO0>;
    PIO1_IRQ_0 => PioInterruptHandler<PIO1>;
    I2C0_IRQ => I2cInterruptHandler<I2C0>;
    UART1_IRQ => BufferedInterruptHandler<UART1>;
    ADC_IRQ_FIFO => AdcInterruptHandler;
    RTC_IRQ => RtcInterruptHandler;
});

/// Helper function to spawn tasks and unwrap, panicking if spawn fails.
/// This is acceptable during initialization as we want to fail fast if we can't spawn a task.
#[allow(clippy::unwrap_used)]
fn spawn_unwrap<S>(spawner: Spawner, token: Result<embassy_executor::SpawnToken<S>, embassy_executor::SpawnError>) {
    spawner.spawn(token.unwrap());
}

/// The main entry point of the program. This is where the tasks are spawned and run.
#[main]
async fn main(spawner: Spawner) {
    info!("Program start");

    // Initialize the peripherals for the RP2040, use reduced clock settings for lower power consumption
    #[allow(clippy::unwrap_used)]
    let mut clock_config = ClockConfig::system_freq(10_000_000).unwrap();
    clock_config.core_voltage = CoreVoltage::V0_90;
    let config = Config::new(clock_config);
    let p = embassy_rp::init(config);

    // Watchdog task - monitors system health and triggers reset if needed
    spawn_unwrap(spawner, watchdog_task(p.WATCHDOG));

    // Orchestrator tasks
    spawn_unwrap(spawner, orchestrator());
    spawn_unwrap(spawner, scheduler());
    spawn_unwrap(spawner, alarm_trigger_task());

    // Green button
    let btn_green = Input::new(p.PIN_20, Pull::Up);
    spawn_unwrap(spawner, button_handler(btn_green, Event::GreenBtn, Button::Green));

    // Blue button
    let btn_blue = Input::new(p.PIN_21, Pull::Up);
    spawn_unwrap(spawner, button_handler(btn_blue, Event::BlueBtn, Button::Blue));

    // Yellow button
    let btn_yellow = Input::new(p.PIN_22, Pull::Up);
    spawn_unwrap(spawner, button_handler(btn_yellow, Event::YellowBtn, Button::Yellow));

    // USB power detector
    let vbus_in = Input::new(p.PIN_28, Pull::None);
    spawn_unwrap(spawner, usb_power_detector(vbus_in));

    // Vsys voltage reader
    let adc = Adc::new(p.ADC, Irqs, AdcConfig::default());
    let vsys_channel = Channel::new_pin(p.PIN_27, Pull::None);
    spawn_unwrap(spawner, vsys_voltage_reader(adc, vsys_channel));

    // Display
    let mut i2c_config = I2cConfig::default();
    i2c_config.frequency = 400_000;
    let i2c = I2c::new_async(p.I2C0, p.PIN_13, p.PIN_12, Irqs, i2c_config);
    spawn_unwrap(spawner, display_handler(i2c));

    // DFPlayer sound handler
    let mut uart_config = UartConfig::default();
    uart_config.baudrate = 9600;
    static TX_BUFFER: StaticCell<[u8; 256]> = StaticCell::new();
    static RX_BUFFER: StaticCell<[u8; 256]> = StaticCell::new();
    let tx_buf = TX_BUFFER.init([0u8; 256]);
    let rx_buf = RX_BUFFER.init([0u8; 256]);
    let uart = BufferedUart::new(p.UART1, p.PIN_4, p.PIN_5, Irqs, tx_buf, rx_buf, uart_config);
    let dfplayer_pwr = Output::new(p.PIN_6, Level::Low);
    let dfplayer_busy = Input::new(p.PIN_3, Pull::None);
    spawn_unwrap(spawner, sound_handler(uart, dfplayer_pwr, dfplayer_busy));

    // Alarm settings persistence
    const FLASH_SIZE: usize = 2 * 1024 * 1024;
    let flash = Flash::<_, Async, FLASH_SIZE>::new(p.FLASH, p.DMA_CH4);
    spawn_unwrap(spawner, alarm_settings_handler(flash));

    // RTC manager task - must be spawned before time_updater
    let rtc = Rtc::new(p.RTC, Irqs);
    spawn_unwrap(spawner, rtc_manager_task(rtc));

    // Time updater with WiFi
    let wifi_peripherals = crate::task::time_updater::WifiPeripherals {
        pwr_pin: p.PIN_23,
        cs_pin: p.PIN_25,
        pio: p.PIO0,
        dio_pin: p.PIN_24,
        clk_pin: p.PIN_29,
        dma_ch: p.DMA_CH0,
    };
    spawn_unwrap(spawner, time_updater(spawner, wifi_peripherals));

    // Neopixel light effects
    let Pio { mut common, sm0, .. } = Pio::new(p.PIO1, Irqs);
    let ws2812_program = PioWs2812Program::new(&mut common);
    let neopixel = PioWs2812::new(&mut common, sm0, p.DMA_CH2, p.PIN_15, &ws2812_program);
    let neopixel_pwr = Output::new(p.PIN_14, Level::Low);
    spawn_unwrap(spawner, light_effects_handler(neopixel, neopixel_pwr));

    // Button LEDs controller
    let button_leds_control = Output::new(p.PIN_26, Level::Low);
    spawn_unwrap(spawner, button_leds_handler(button_leds_control));
}

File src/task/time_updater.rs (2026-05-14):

//! # Time Updater Task
//! This module contains the task that updates the RTC using NTP.
//! The task is responsible for connecting to a wifi network, querying an NTP server, applying CET/CEST rules, and updating the RTC.
//!
//! # populate constants SSID and PASSWORD
//! make sure to have a `wifi_config.json` file in the config folder formatted as follows:
//!```json
//!  {
//!     "ssid": "some_ssid_here",
//!     "password": "some_password_here"
//! }
//! ```
//! also make sure that `build.rs` loads the `wifi_config.json` file and writes it to `wifi_secrets.rs`

include!(concat!(env!("OUT_DIR"), "/wifi_secrets.rs"));

use cyw43::JoinOptions;
use cyw43_pio::{DEFAULT_CLOCK_DIVIDER, PioSpi};
use defmt::{info, unwrap, warn};
use defmt_rtt as _;
use embassy_executor::Spawner;
use embassy_futures::select::select;
use embassy_net::{
    Config, DhcpConfig, IpEndpoint, StackResources, dns,
    udp::{PacketMetadata, UdpSocket},
};
use embassy_rp::{
    Peri,
    clocks::RoscRng,
    gpio::{Level, Output},
    peripherals::{self, DMA_CH0, PIO0},
    pio::Pio,
};
use embassy_sync::{blocking_mutex::raw::CriticalSectionRawMutex, signal::Signal};
use embassy_time::{Duration, Timer, with_timeout};
use panic_probe as _;
use static_cell::StaticCell;

use embassy_rp::rtc::{DateTime, DayOfWeek};

use crate::{
    Irqs,
    event::{Event, send_event},
    task::watchdog::{TaskId, report_task_failure, report_task_success},
};

/// Signal for suspending the time updater task
static TIME_UPDATER_SUSPEND_SIGNAL: Signal<CriticalSectionRawMutex, ()> = Signal::new();

/// Signal for resuming the time updater task
static TIME_UPDATER_RESUME_SIGNAL: Signal<CriticalSectionRawMutex, ()> = Signal::new();

/// Signals the time updater to suspend
pub fn signal_time_updater_suspend() {
    TIME_UPDATER_SUSPEND_SIGNAL.signal(());
}

/// Signals the time updater to resume
pub fn signal_time_updater_resume() {
    TIME_UPDATER_RESUME_SIGNAL.signal(());
}

/// Checks if the time updater suspend signal has been signaled
fn is_time_updater_suspend_signaled() -> bool {
    TIME_UPDATER_SUSPEND_SIGNAL.signaled()
}

/// Resets the time updater suspend signal
fn reset_time_updater_suspend_signal() {
    TIME_UPDATER_SUSPEND_SIGNAL.reset();
}

/// Waits for the time updater resume signal
async fn wait_for_time_updater_resume() {
    TIME_UPDATER_RESUME_SIGNAL.wait().await;
}

/// `WiFi` peripheral resources needed for the time updater task
pub struct WifiPeripherals {
    /// Power pin for `WiFi` module
    pub pwr_pin: Peri<'static, peripherals::PIN_23>,
    /// Chip select pin for `WiFi` module
    pub cs_pin: Peri<'static, peripherals::PIN_25>,
    /// `PIO` peripheral for `WiFi` communication
    pub pio: Peri<'static, peripherals::PIO0>,
    /// Data I/O pin for `WiFi` module
    pub dio_pin: Peri<'static, peripherals::PIN_24>,
    /// Clock pin for `WiFi` module
    pub clk_pin: Peri<'static, peripherals::PIN_29>,
    /// `DMA` channel for `WiFi` communication
    pub dma_ch: Peri<'static, peripherals::DMA_CH0>,
}

/// Type alias for the RTC mutex.
/// Static cell for `CYW43` `WiFi` state.
static WIFI_STATE: StaticCell<cyw43::State> = StaticCell::new();

/// Static cell for network stack.
static NETWORK_STACK: StaticCell<embassy_net::Stack<'_>> = StaticCell::new();

/// Static cell for network stack resources.
static NETWORK_RESOURCES: StaticCell<StackResources<5>> = StaticCell::new();

/// Static buffers for NTP UDP communication (protected by mutex to allow reuse).
static NTP_BUFFERS: embassy_sync::mutex::Mutex<
    embassy_sync::blocking_mutex::raw::CriticalSectionRawMutex,
    Option<NtpBuffers>,
> = embassy_sync::mutex::Mutex::new(Some(NtpBuffers::new()));

/// NTP UDP communication buffers.
#[allow(clippy::struct_field_names)]
struct NtpBuffers {
    /// Receive packet metadata
    rx_meta: [PacketMetadata; 4],
    /// Receive buffer
    rx_buffer: [u8; 128],
    /// Transmit packet metadata
    tx_meta: [PacketMetadata; 4],
    /// Transmit buffer
    tx_buffer: [u8; 128],
}

impl NtpBuffers {
    /// Create new NTP buffers initialized to zero.
    const fn new() -> Self {
        Self {
            rx_meta: [PacketMetadata::EMPTY; 4],
            rx_buffer: [0; 128],
            tx_meta: [PacketMetadata::EMPTY; 4],
            tx_buffer: [0; 128],
        }
    }
}

/// Configuration for the time updater task.
pub struct TimeUpdater {
    /// `WiFi` SSID
    ssid: &'static str,
    /// `WiFi` password
    password: &'static str,
    /// NTP server hostname
    ntp_server: &'static str,
    /// Seconds to wait before refreshing time
    refresh_after_secs: u64,
    /// Seconds to wait before retrying on error
    retry_after_secs: u64,
    /// Timeout duration for network operations
    timeout_duration: Duration,
}

impl TimeUpdater {
    /// Creates a new `TimeUpdater` instance with default configuration.
    pub const fn new() -> Self {
        Self {
            ssid: SSID,
            password: PASSWORD,
            ntp_server: "europe.pool.ntp.org",
            refresh_after_secs: 21_600, // 6 hours
            retry_after_secs: 30,
            timeout_duration: Duration::from_secs(15),
        }
    }

    /// Returns the `WiFi` credentials as a tuple of (ssid, password).
    const fn credentials(&self) -> (&str, &str) {
        (self.ssid, self.password)
    }

    /// Returns the NTP server hostname.
    const fn ntp_server(&self) -> &str {
        self.ntp_server
    }
}

/// `WiFi` driver task that runs the `CYW43` firmware.
#[embassy_executor::task]
async fn wifi_task(runner: cyw43::Runner<'static, Output<'static>, PioSpi<'static, PIO0, 0, DMA_CH0>>) -> ! {
    runner.run().await
}

/// Network stack task that handles TCP/IP networking.
#[embassy_executor::task]
async fn net_task(mut runner: embassy_net::Runner<'static, cyw43::NetDriver<'static>>) -> ! {
    runner.run().await
}
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

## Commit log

2024-06-14 2 create the main structure of the project include the buttonmanager class to demonstrate viability (#3)
    * type hints confuse me more than they help
    * save
    * can launch and attach debug session
    * chore: Enable type hints in Rust analyzer and update dependencies
    * first implementation of a button task, changes to main including some comments
    * add blue and yellow buttons
    * chore: Add StateManager and StateManagement trait
    * upd ci definition
    * target in ci
    * ci 3
    * ci 4
    * ci 5
    * pdate dependencies and fix cargo build issues
    ---------
    [btn_mgr.rs, main.rs]
2024-06-16 4-add-wifi-connection (#5)
    * Update rust-toolchain.toml to use stable channel
    * safely use wifi credentials via build.rs and include! in wifi_mgr
    * better orga and errors when reading wifi secrets
    * wifi connects
    * build fails: missing wifi config file, need a dummy file for ci
    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
    [main.rs]
2024-06-26 8-update-rtc (#9)
    * Make WifiManager public, so that we can later acess its state
    * StateManager comments
    * Refactor WifiManager to use StringUtils for string conversions
    * add time_mgr, still need to refactor wifi_mgr to enable web requests
    * compiles
    * clippy
    * cleaning a bit
    * clean
    * we got connection, rettrieve data and have mnaged the strings stuff better
    * rename to time_updater
    * tidy
    * trying
    * can parse response
    * some cleaning, i do not need the state structs after all
    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
    [main.rs, time_updater.rs]
2024-06-27 10-joining-wifi-stalls-the-system (#11)
2024-07-23 19-introduce-power-information (#31)
2024-08-03 tune vbus edge and vsys voltage (#44)
2024-08-08 Trigger vsys voltage reading on usb edge, some tidying (#47)
2024-08-17 held button sends multiple events down the channel; remove presses which was unused (#54)
2025-10-16 Prepare for major refactor -> step 1 update everything (#62)
    - Bump Rust edition to 2024 and set toolchain to 1.90.0 - Update embassy
    and related crates to latest git revs - Switch from dfplayer-serial to
    dfplayer-async - Update ws2812-async usage and light effects handler for
    new API - Refactor resource handling to use reborrow and mut where
    needed - Update time_updater for new embassy-net and cyw43 APIs - Add
    RTC interrupt binding and task for static RTC management - Update
    panic-probe, heapless, reqwless, and other dependencies - Remove
    unused/obsolete features and dependencies - General code cleanup for
    compatibility with new APIs
    [display.rs, light_effects.rs, main.rs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]
2025-10-17 Use rtc alarm (#64)
    * Configure defmt release logging and update README
    Document DEFMT_LOG usage in README and add a defmt release profile to
    compile out debug/info logs; recommend DEFMT_LOG=warn to prevent RTT
    buffer overflow when running standalone
    * Add RTC alarm trigger task and refactor scheduler
    Introduce task/alarm_trigger.rs to schedule and await RTC alarms and add
    ALARM_SCHEDULE_UPDATE_SIGNAL / ALARM_SCHEDULE_DISABLE_SIGNAL for
    coordination. Move alarm scheduling/triggering out of scheduler;
    scheduler now relies on the RTC and uses alarm_enabled to determine
    update frequency. Downgrade several non-fatal error logs to warn where
    initialization/timeouts are recoverable.
    * Update s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
    [display.rs, light_effects.rs, main.rs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]
2025-10-18 Sober up warnings (#65)
    * Run all tasks on main executor
    Remove the high-priority InterruptExecutor, SWI_IRQ_1 handler, and the
    core1 spawn. Use the single main spawner for all tasks (including
    light_effects). Update imports accordingly (use defmt::info and drop
    interrupt/multicore types).
    * Suppress Clippy warnings in build.rs
    * Add package metadata to Cargo.toml
    * Reorder task_messages imports
    * Update main.rs
    * Use brace formatting and add docs in build.rs
    * Make DateTime formatting non-panicking and borrowed
    Change convert_datetime_to_str to take &DateTime and avoid unwraps;
    ignore padding failures so capacity errors skip padding instead of
    panicking. Add a doc comment for String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
    [display.rs, light_effects.rs, main.rs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]
2025-10-22 Formatting and settings (#69)
    * Add script to flash Wi-Fi firmware via probe-rs
    * Set rust-analyzer target to thumbv6m-none-eabi
    Disable cargo.allTargets to limit analysis to the specified embedded
    target
    * Add rustfmt config; reformat and tidy imports
2025-11-10 Better schematic (#70)
    * Add button LEDs task and adjust DFPlayer pin
    * Add button LEDs task
    * Add Pi Pico alarm clock KiCad project files
    * Update README with flashing instructions and BOM
    Replace elf2uf2-rs steps with picotool flash/uf2 commands and note
    elf2uf2-rs incompatibility with Rust 1.89+. Expand Components into a
    detailed Bill of Materials and point circuit schematic to
    circuit/pi-pico-alarmclock/. Remove binary CDDX and PNG circuit files.
    * Add TP4056 charger footprint and fix orientations
    * Document LED ring push buttons in README
    * First Layout draft, no tracks yet
    * Routing V1
    * Set drillshape to 0 in KiCad PCB file
    * Finish V0.1, gerbers
    [pi-pico-alarmclock-B_Cu.gbr, pi-pico-alarmclock-B_Mask.gbr, pi-pico-alarmclock-B_Paste.gbr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]
2025-11-10 Use PIO-based WS2812 driver (#71)
    * Use PIO-based WS2812 driver
    * Apply brightness per-LED and optimize iteration
    Compute alarm_brightness once and scale each LED color in the noise
    effect instead of applying brightness to the whole array. Use
    Iterator::take in apply_brightness to avoid a manual bounds check loop.
    [light_effects.rs, main.rs]
2025-11-10 Reposition value labels in schematic
    Remove fields_autoplaced flags for several components Adjust position
    and rotation of value labels for BTN GREEN, BTN YELLOW, BTN BLUE, and
    IRLZ44N.
    [pi-pico-alarmclock.kicad_sch]
2025-11-20 Test build (#72)
    * move wifi firmware
    * worldtimeapi is no longer available
    * Use PIN_19 for WS2812 light effects
    * remove unnessecary kicad files
    * Add RTC manager and initialization flow
    Replace the global RTC mutex with a dedicated rtc_manager task that owns
    the RTC and exposes async APIs. Update time_updater, scheduler, display,
    and alarm_trigger to use the manager. Add Initializing mode and
    SystemReady event to coordinate RTC/time and alarm-settings startup;
    display an initializing screen and keep LEDs off until ready. Ensure
    alarms are always scheduled in the future and improve alarm wait/
    scheduling logic. Misc: always send alarm-settings event (use defaults
    if missing), apply qu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
    [pi-pico-alarmclock-B_Cu.gbr, pi-pico-alarmclock-B_Mask.gbr, pi-pico-alarmclock-B_Paste.gbr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]
2025-11-20 Replace prototype PNG with JPG (#73)
2025-11-22 More setup options (#74)
    * Add system settings, UI and persistence
    Introduce SystemSettings (volume, clock brightness) with flash
    persistence (keys 3-4) and runtime propagation.
    Add UI modes for Settings / SetVolume / SetClockBrightness /
    SetTimeManual, display rendering and button handlers. Provide runtime
    update signals for NeoPixel brightness and DFPlayer volume, and a manual
    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
2025-12-06 Fix hangs (#75)
    Refactored event-driven async operations into direct function calls to reduce event queue overhead and potential race conditions.
    Key changes:
    - Removed six event variants and replaced event-based communication with direct handler calls
    - Added interruptible cooldown mechanism in alarm trigger task
    - Improved analog clock update interval from 3740ms to 1000ms
    [orchestrate.rs]
2025-12-11 New enclosure (#76)
    * remove outdated Fusion360 files
    * new enclosure FreeCAD project
    * finished enclosure, pre-testing
    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
    [PiPicoAlarmclock-Body.3mf, PiPicoAlarmclock-Front.3mf, PiPicoAlarmclock.FCStd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]
2025-12-12 Refinements (#77)
    * Replace alarm_expirer with DFPlayer busy pin
    Remove alarm_expirer task and its signal/spawn. Make sound_handler
    accept a DFPlayer busy input pin, wait for it to go high to detect
    playback end, and emit Event::AlarmStop. Update main to instantiate and
    pass dfplayer_busy to the sound task.
    * Shorten alarm interval and reset stop signal
    Decrease scheduler wait from 60s to 10s when alarm is enabled to allow
    quicker task updates while the RTC handles alarms.
    Reset STOP_ALARM_WAIT_SIGNAL before entering the alarm wait to avoid
    immediately exiting if the signal remained set
    * changes to enclosure after tes print
    * Rename busy wait fn to wait_for_music_end
    Import select an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
    [PiPicoAlarmclock-Body.3mf, PiPicoAlarmclock-Front.3mf, PiPicoAlarmclock.FCStd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]
2025-12-14 First complete build (#78)
    * some tweaks to the enclosure to make things fit and print better
    * Add Alarm Mode and Assembly sections to README
    Replace single prototype image with two centered photos and captions.
    Add Alarm Mode image and caption. Add Assembly photos (breadboard and
    finished build) with descriptive captions. Remove "Power switch" item
    from the Interface list.
    * add new images
    * Rearrange README images and remove alarm section
    [PiPicoAlarmclock-Body.3mf, PiPicoAlarmclock-Front.3mf, PiPicoAlarmclock.FCStd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]
2025-12-16 Things found while real life testing (#79)
    * Add noise filtering for power detection
    Use median filtering for VSYS readings, debounce VBUS, and add 0.1V
    hysteresis to suppress display flicker. Add moving_median dependency and
    document the strategy in README
    * Do not stop sound on standby, fixes race condition after going out of
    standby
    * Issue with not playing sound after standby and after alarms that had
    quit by the end of the song: Race of pending sound stop signal. Solution
    is to track DFPlayer power state and gate stop signal to only when it is
    even powered.
    * Add ClockTime and avoid redundant LED writes
    * Bump version to 0.7.2 and add lessons learned
    * Use PIN_15 for WS2812 instea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
    [pi-pico-alarmclock.kicad_pcb, pi-pico-alarmclock.kicad_sch]
2026-01-06 Update enclosure 3D and CAD files (#81)
    Remove stale PiPicoAlarmclock.20251213-100058.FCBak backup
    [PiPicoAlarmclock-Body.3mf, PiPicoAlarmclock.FCStd, print.3mf]
2026-01-06 Wrong resistors on pcb (#82)
    * Bump version and use 220kΩ voltage divider
    * Update resistors to 220K and bump revision
    Set several 200K resistor values to 220K in schematic and PCB. Bump
    project version/revision to v0.4 (01.2026 / 2026-01-06). Regenerate PCB
    footprint UUIDs.
    [pi-pico-alarmclock.kicad_pcb, pi-pico-alarmclock.kicad_sch]
2026-05-12 Dark if alarm active (#83)
    * Float and restore Neopixel data pin
    Use direct PAC access to switch GP15 to a floating SIO input before
    cutting Neopixel power and restore it to PIO1 before powering on. This
    breaks a parasitic current path through the WS2812B DIN line. PAC access
    is used to avoid re-taking the pin from the PIO (so Flex is not used).
    * Bump version to 0.8.0 and update deps
    * Add display sleep state and timeout handling
    -> display goes off if alarm is active so there is no light pollution.
    The oled is too bright even on dimmest setting.
    [display.rs, light_effects.rs, orchestrate.rs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]
2026-05-14 Refactoring after real-life deadlock (#84)
    * Refactoring after real-life deadlock
    We had held locks on system state too liberally and this was refactored
    to minimize lock times. The last change with the screen deactivation
    surfaced an older problem which should no be fixed.
    * Update orchestrate.rs
    [orchestrate.rs]
2026-05-14 More reliable time updater (#85)
    * retries of http requests, timeouts for requests
    * switch to ntp server entirely, which should now be much more reliable
    * new version, reintroduce logs
    * review
